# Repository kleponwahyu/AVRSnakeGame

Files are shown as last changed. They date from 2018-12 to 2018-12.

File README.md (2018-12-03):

8-bit Snake Game with AVR!
Complete with the schematic, board design, and the program!

The board design can be implemented for other games that uses low pixel count, for including tetris, car race and many more! (but no code yet...)

Note:
- The code is in C
- The board design and schematics are in EAGLE
- Already working as intended, but the pcb still need cleaning and can be shrinked.
- The Dot Matrix is in wrong angle, so physical and logical coordinates needed, and it takes memory space and clock. Will fix this for sure!

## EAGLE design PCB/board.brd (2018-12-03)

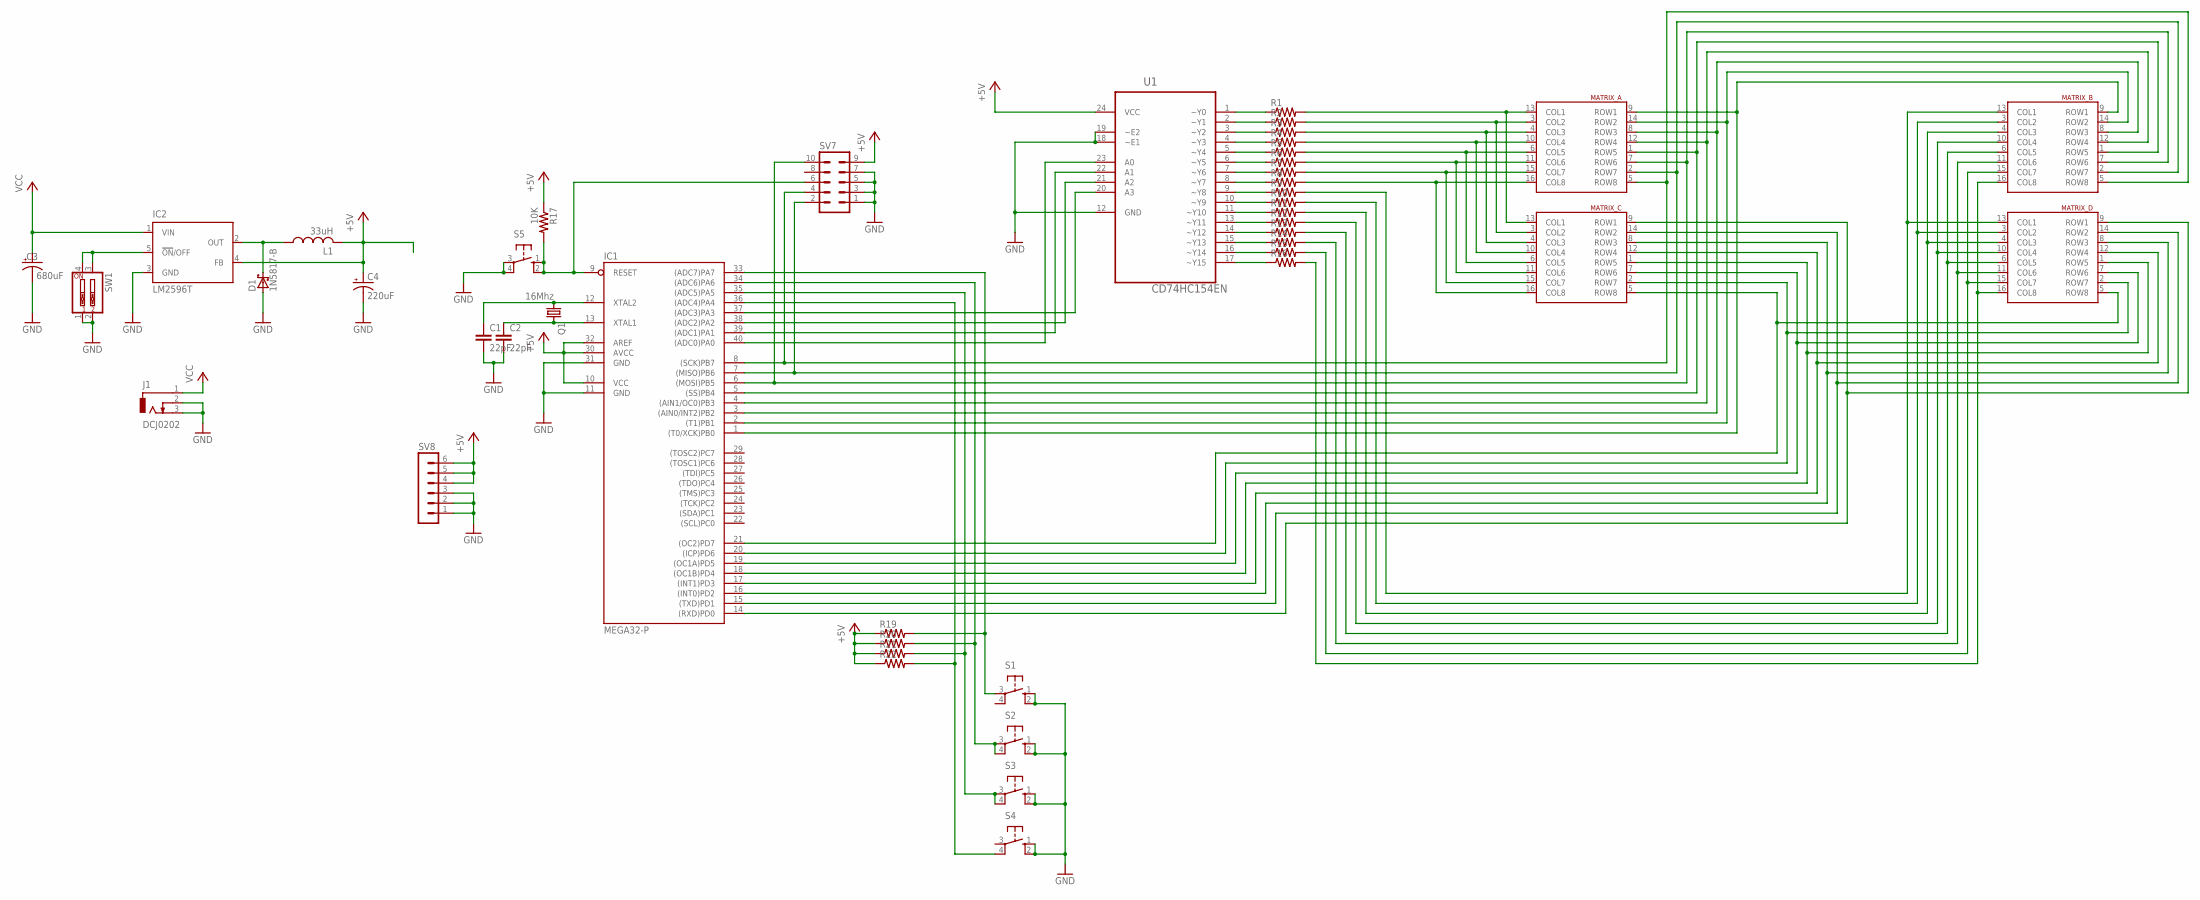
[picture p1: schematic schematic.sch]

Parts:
C1, C2: 22pF; C025-024X044
C3: 680uF; E3,5-8
C4: 220uF; E3,5-8
D1: 1N5817-B; DO41-7.6
IC1: MEGA32-P; DIL40
IC2: LM2596T; T05D
J1: DCJ0202
L1: 33uH; 0207/10
MATRIX_A: LED_8X8_MATRIXYGD2/A; MATRIX_8X8_38MM
MATRIX_B: LED_8X8_MATRIXYGD2/A; MATRIX_8X8_38MM
MATRIX_C: LED_8X8_MATRIXYGD2/A; MATRIX_8X8_38MM
MATRIX_D: LED_8X8_MATRIXYGD2/A; MATRIX_8X8_38MM
Q1: 16Mhz; HC49/S
R1, R2, R3, R4, R5, R6, R7, R8, R9, R10, R11, R12, R13, R14, R15, R16: R-US_0204/2V; 0204V
R17: 10K; 0204/7
R19, R20, R21, R22: R-US_0204/7; 0204/7
S1, S2, S3, S4, S5: 10-XX; B3F-10XX
SV7: MA05-2
SV8: MA06-1
SW1: SW_DIP-2; EDG-02
U1: CD74HC154EN; DIP254P762X508-24

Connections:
+5V: C4.+, IC1.10 (VCC), IC1.30 (AVCC), IC1.32 (AREF), IC2.4 (FB), L1.2, R17.1, R19.1, R20.1, R21.1, R22.1, SV7.9, SV8.4, SV8.5, SV8.6, U1.24 (VCC)
GND: C1.2, C2.2, C3.-, C4.-, D1.A, IC1.11 (GND), IC1.31 (GND), IC2.3 (GND), J1.2, J1.3, S1.1 (S), S1.2 (S1), S2.1 (S), S2.2 (S1), S3.1 (S), S3.2 (S1), S4.1 (S), S4.2 (S1), S5.3, S5.4 (P1), SV7.1, SV7.3, SV7.5, SV7.7, SV8.1, SV8.2, SV8.3, SW1.1, SW1.2, U1.12 (GND), U1.18 (~E1), U1.19 (~E2)
unnamed: R1.1, U1.1 (~Y0)
unnamed: R2.1, U1.2 (~Y1)
unnamed: R3.1, U1.3 (~Y2)
unnamed: R4.1, U1.4 (~Y3)
unnamed: R5.1, U1.5 (~Y4)
unnamed: R6.1, U1.6 (~Y5)
unnamed: R7.1, U1.7 (~Y6)
unnamed: R8.1, U1.8 (~Y7)
unnamed: R9.1, U1.9 (~Y8)
unnamed: R10.1, U1.10 (~Y9)
unnamed: R11.1, U1.11 (~Y10)
unnamed: R12.1, U1.13 (~Y11)
unnamed: R13.1, U1.14 (~Y12)
unnamed: R14.1, U1.15 (~Y13)
unnamed: R15.1, U1.16 (~Y14)
unnamed: R16.1, U1.17 (~Y15)
unnamed: MATRIX_A.13 (COL1), MATRIX_C.13 (COL1), R1.2
unnamed: MATRIX_A.3 (COL2), MATRIX_C.3 (COL2), R2.2
unnamed: MATRIX_A.4 (COL3), MATRIX_C.4 (COL3), R3.2
unnamed: MATRIX_A.10 (COL4), MATRIX_C.10 (COL4), R4.2
unnamed: MATRIX_A.6 (COL5), MATRIX_C.6 (COL5), R5.2
unnamed: MATRIX_A.11 (COL6), MATRIX_C.11 (COL6), R6.2
unnamed: MATRIX_A.15 (COL7), MATRIX_C.15 (COL7), R7.2
unnamed: MATRIX_A.16 (COL8), MATRIX_C.16 (COL8), R8.2
unnamed: IC1.7 ((MISO)PB6), MATRIX_A.2 (ROW7), MATRIX_B.2 (ROW7), SV7.2
unnamed: IC1.8 ((SCK)PB7), MATRIX_A.5 (ROW8), MATRIX_B.5 (ROW8), SV7.4
unnamed: IC1.5 ((SS)PB4), MATRIX_A.1 (ROW5), MATRIX_B.1 (ROW5)
unnamed: IC1.3 ((AIN0/INT2)PB2), MATRIX_A.8 (ROW3), MATRIX_B.8 (ROW3)
unnamed: IC1.1 ((T0/XCK)PB0), MATRIX_A.9 (ROW1), MATRIX_B.9 (ROW1)
unnamed: IC1.15 ((TXD)PD1), MATRIX_C.14 (ROW2), MATRIX_D.14 (ROW2)
unnamed: IC1.17 ((INT1)PD3), MATRIX_C.12 (ROW4), MATRIX_D.12 (ROW4)
unnamed: IC1.20 ((ICP)PD6), MATRIX_C.2 (ROW7), MATRIX_D.2 (ROW7)
unnamed: IC1.9 (RESET), R17.2, S5.1 (S), S5.2 (S1), SV7.6
unnamed: MATRIX_B.15 (COL7), MATRIX_D.15 (COL7), R15.2
unnamed: C2.1, IC1.13 (XTAL1), Q1.2
unnamed: MATRIX_B.6 (COL5), MATRIX_D.6 (COL5), R13.2
unnamed: C1.1, IC1.12 (XTAL2), Q1.1
unnamed: MATRIX_B.4 (COL3), MATRIX_D.4 (COL3), R11.2
unnamed: MATRIX_B.13 (COL1), MATRIX_D.13 (COL1), R9.2
unnamed: IC1.39 ((ADC1)PA1), U1.22 (A1)
unnamed: IC1.37 ((ADC3)PA3), U1.20 (A3)
unnamed: IC1.34 ((ADC6)PA6), R20.2, S2.3, S2.4 (P1)
unnamed: IC1.36 ((ADC4)PA4), R22.2, S4.4 (P1)
unnamed: MATRIX_B.3 (COL2), MATRIX_D.3 (COL2), R10.2
unnamed: IC1.2 ((T1)PB1), MATRIX_A.14 (ROW2), MATRIX_B.14 (ROW2)
unnamed: MATRIX_B.10 (COL4), MATRIX_D.10 (COL4), R12.2
unnamed: MATRIX_B.11 (COL6), MATRIX_D.11 (COL6), R14.2
unnamed: IC1.4 ((AIN1/OC0)PB3), MATRIX_A.12 (ROW4), MATRIX_B.12 (ROW4)
unnamed: MATRIX_B.16 (COL8), MATRIX_D.16 (COL8), R16.2
unnamed: IC1.6 ((MOSI)PB5), MATRIX_A.7 (ROW6), MATRIX_B.7 (ROW6), SV7.10
unnamed: IC1.14 ((RXD)PD0), MATRIX_C.9 (ROW1), MATRIX_D.9 (ROW1)
unnamed: IC1.16 ((INT0)PD2), MATRIX_C.8 (ROW3), MATRIX_D.8 (ROW3)
unnamed: IC1.18 ((OC1B)PD4), MATRIX_C.1 (ROW5), MATRIX_D.1 (ROW5)
unnamed: IC1.19 ((OC1A)PD5), MATRIX_C.7 (ROW6), MATRIX_D.7 (ROW6)
unnamed: IC1.21 ((OC2)PD7), MATRIX_C.5 (ROW8), MATRIX_D.5 (ROW8)
unnamed: IC1.35 ((ADC5)PA5), R21.2, S3.3, S3.4 (P1)
unnamed: IC1.33 ((ADC7)PA7), R19.2, S1.3
unnamed: IC1.40 ((ADC0)PA0), U1.23 (A0)
unnamed: IC1.38 ((ADC2)PA2), U1.21 (A2)
unnamed: D1.C, IC2.2 (OUT), L1.1
unnamed: IC2.5 (!ON!/OFF), SW1.3, SW1.4
VCC: C3.+, IC2.1 (VIN), J1.1

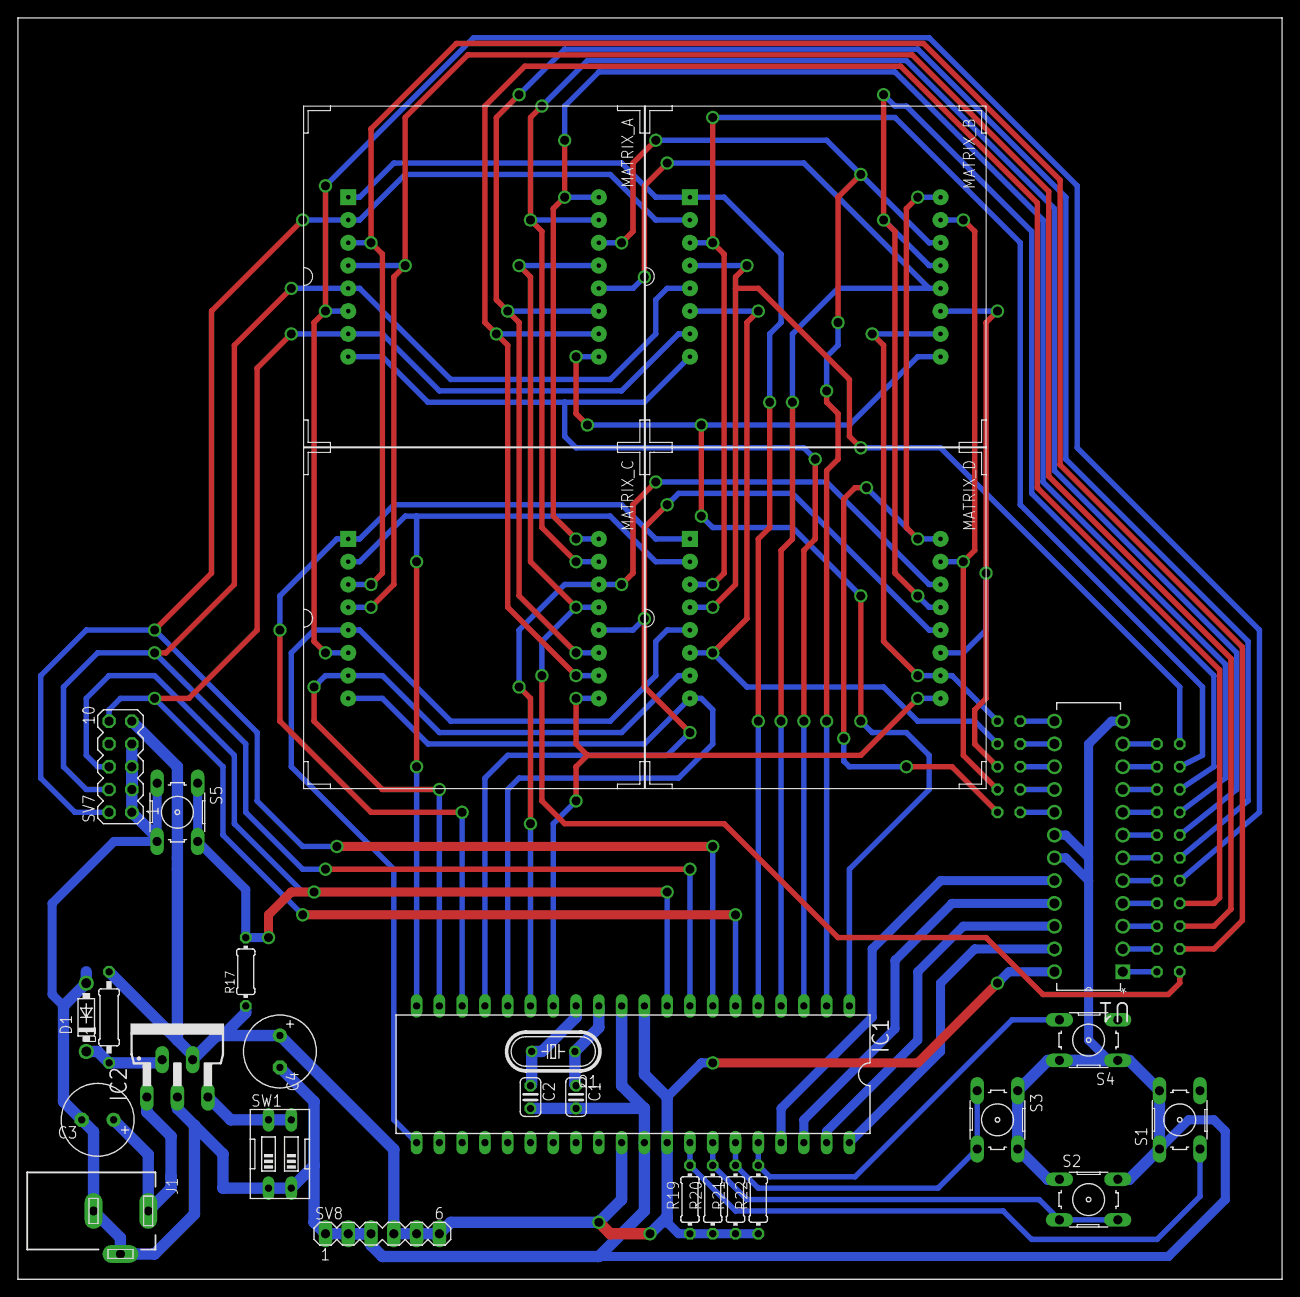
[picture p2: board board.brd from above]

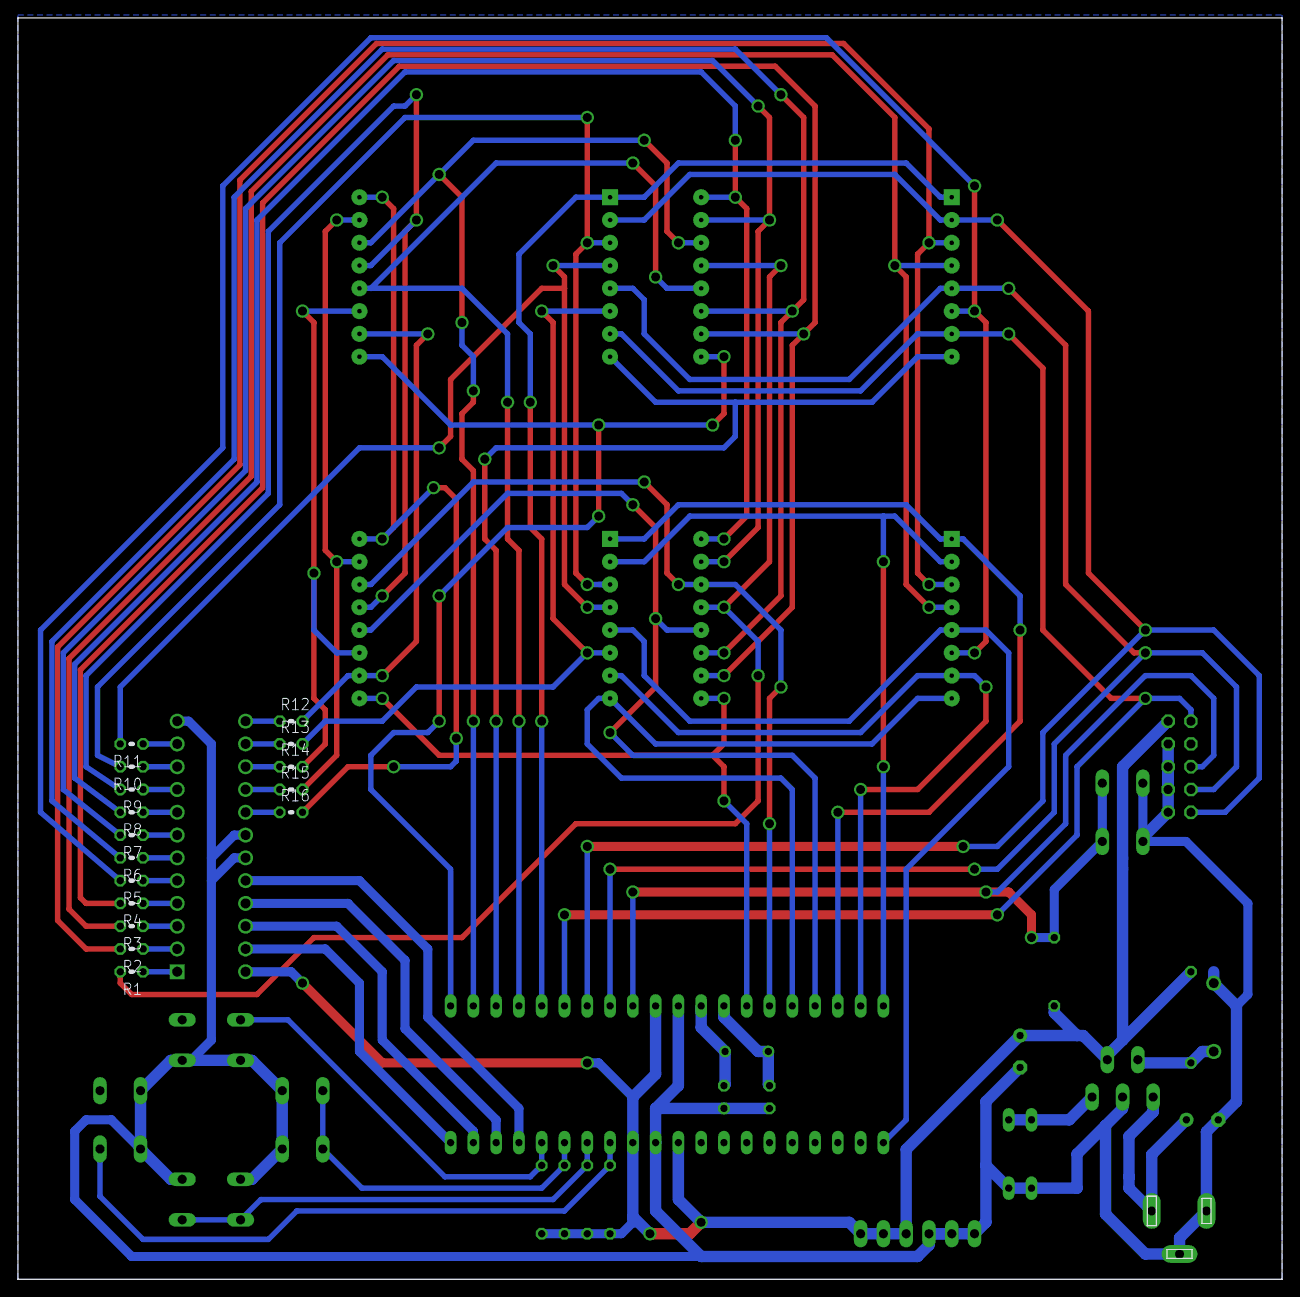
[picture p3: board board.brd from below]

Board: 2 copper layers, 140.9 x 140.6 mm, 44 parts (16 on the bottom side), 64 nets.

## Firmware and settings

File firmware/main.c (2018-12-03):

/* Name: main.c
 * Author: Wahyu Berlianto
 * Copyright: <insert your copyright message here>
 * License: <insert your license reference here>
 */

#include <avr/io.h>
#include <util/delay.h>

struct Location {
  int x, y;
};
struct Location currentLocation[128];
int displayLoop, snakePath, displayCount, snakeLength, snakeLengthCounter, eating = 0, lose, differentPath = 0;

struct Location food;

void borderCheck() {
  if(currentLocation[0].x < 0 || currentLocation[0].x > 15 || currentLocation[0].y < 0 || currentLocation[0].y > 15) {
    lose = 1;
  }
}

void movement(int x) {
  int temp;
  //check if eating or not
  if(food.x == currentLocation[0].x && food.y == currentLocation[0].y) {
    for(temp = snakeLength; temp >= 0; temp--) {
      currentLocation[temp + 1] = currentLocation[temp];
    }
    snakeLength++;
    food.x = rand() % 16;
    food.y = rand() % 16;
  }
  else if(snakeLength > 0) {
    for(temp = 1; temp <= snakeLength; temp++) {
      if(currentLocation[0].x == currentLocation[temp].x && currentLocation[0].y == currentLocation[temp].y) {
        lose = 1;
      }
    }

    for(temp = snakeLength; temp > 0; temp--) {
      currentLocation[temp] = currentLocation[temp - 1];
    }
  }
  switch(x) {
    case 0:
     currentLocation[0].y--;
     break;
    case 1:
     currentLocation[0].x--;
     break;
    case 2:
     currentLocation[0].y++;
     break;
    case 3:
     currentLocation[0].x++;
     break;
   }

  //Cek lokasi apabila lewat border
  borderCheck();
}

void scanButton() {
  if(bit_is_clear(PINA, 4) && differentPath == 0) {
    if((snakePath % 2) != 0) {
      snakePath = 0;
      differentPath = 1;
    }
  }
  else if(bit_is_clear(PINA, 5) && differentPath == 0) {
    if((snakePath % 2) != 1) {
      snakePath = 1;
      differentPath = 1;
    }
  }
  else if(bit_is_clear(PINA, 6) && differentPath == 0) {
    if((snakePath % 2) != 0) {
      snakePath = 2;
      differentPath = 1;
    }
  }
  else if(bit_is_clear(PINA, 7) && differentPath == 0) {
    if((snakePath % 2) != 1) {
      snakePath = 3;
      differentPath = 1;
    }
  }
}

void display(int x, int y) {
  if(x < 8 && y < 8) {         //Dot Matrix A
    PORTD = 0x00;
    x = 7 - x;
    PORTB = (1 << x);
  }
  else if(x > 7 && y < 8) {   //Dot Matrix B
    PORTD = 0x00;
    x = 15 - x;
    PORTB = (1 << x);
    y = y + 8;
  }
  else if(x < 8 && y > 7) {   //Dot Matrix C
    PORTB = 0x00;
    x = 7 - x;
    PORTD = (1 << x);
    y = y - 8;
  }
    else if(x > 7 && y > 7) {   //Dot Matirx D
    PORTB = 0x00;
    x = 15 - x;
    PORTD = (1 << x);
  }

  PORTA = y;
  _delay_us(5);
  PORTB = PORTD = 0x00;
}

int main(void) {
  /* insert your hardware initialization here */
  DDRB = DDRD = 0xFF;
  DDRA = 0x0F;
  int x, y, delay;

  loses:
  PORTB = PORTD = 0x00;
  _delay_ms(50);
  lose = 0;
  food.x = rand() % 16;
  food.y = rand() % 16;
  currentLocation[0].x = rand() % 16;
  currentLocation[0].y = rand() % 16;
  snakePath = rand() % 4;
  snakeLength = 0;

  while(1) {
    //Untuk merubah arah pergerakan
    movement(snakePath);
    if (lose == 1) {
      goto loses;
    }
    //Tampilkan sesuai lokasi logical
    delay = 1000 / (snakeLength + 1);

    for(displayCount = 0; displayCount < delay; displayCount++) {
      for(snakeLengthCounter = 0; snakeLengthCounter <= snakeLength; snakeLengthCounter++) {

        x = currentLocation[snakeLengthCounter].x;
        y = currentLocation[snakeLengthCounter].y;

        display(x, y);

      }
      //Display food
      x = food.x;
      y = food.y;
      display(x,y);

      scanButton();
      if(differentPath == 1) {
        differentPath = 0;
        break;
      }
    }
  }
  return 0;   /* never reached */
}

// void debugDisplay() {
//   for(currentLocation[0].y = 0; currentLocation[0].y < 16; currentLocation[0].y++) {
//     for(currentLocation[0].x = 0; currentLocation[0].x < 16; currentLocation[0].x++) {
//       display(currentLocation[0].x, currentLocation[0].y);
//       _delay_ms(2);
//       PORTB = PORTD = 0x00;
//     }
//   }
// }
